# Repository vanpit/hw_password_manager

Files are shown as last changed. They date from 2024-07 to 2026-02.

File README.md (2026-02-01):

# Instrukcja managera haseł
Urządzenie posiada 3 przyciski: 
G - "góra"; 
D - "dół"; 
E - "enter";

W ekranie głównym: 
	G/D krótko - wybór slotu; 
	G długo - wejście w opcje slotu; 
	D długo - wypisanie starego hasła slotu; 
	E krótko - pisanie użytkownik [TAB] hasło [ENTER]; 
	E długo - pisanie samego hasła; 
	
W ekranie edycji slotu: 
	G/D krótko - wybór sekcji; 
	G długo - wejście w edycję pola; 
	D długo - anulowanie edycji slotu; 
	E długo na "przycisku" - wciśnięcie przycisku; 
	
W ekranie edycji pola tekstowego: 
	G/D krótko - zmiana literek; 
	E krótko - następna literka; 
	E długo na OK - zapisanie pola; 
	
W edycji/wpisywaniu PINu: 
	G/D krótko - wpisane 1 lub 0; 
	E długo na OK - zapisanie PINu; 

# Potrzebne elementy

Płytka ewaluacyjna  STM32F411 Black Pill

Wyświetlacz OLED SSD 1306

Mikroprzełączniki o oznaczeniu w TME B3U-1000PM

Kondensatory ceramiczne 0805 100nF

Przewody połączeniowe

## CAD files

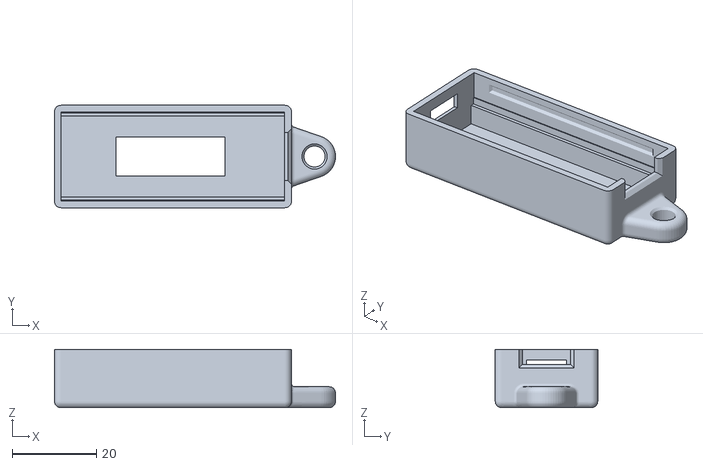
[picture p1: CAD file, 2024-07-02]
STL/Main case.stl
66.9 x 24.4 x 13.9

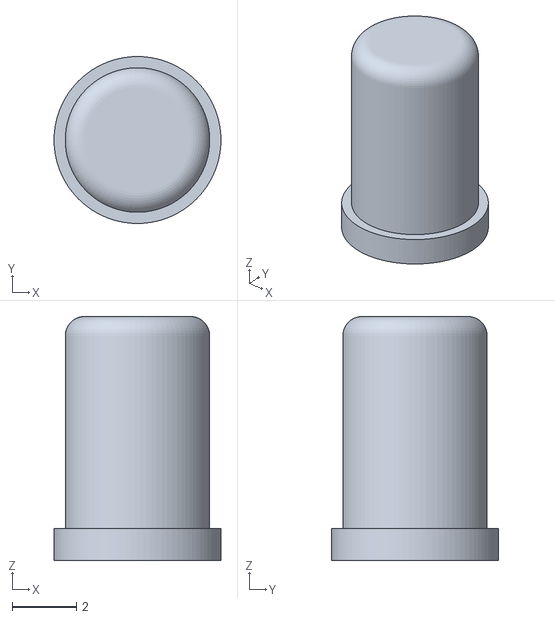
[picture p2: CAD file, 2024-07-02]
STL/Button 2.stl
5.20 x 5.20 x 7.60

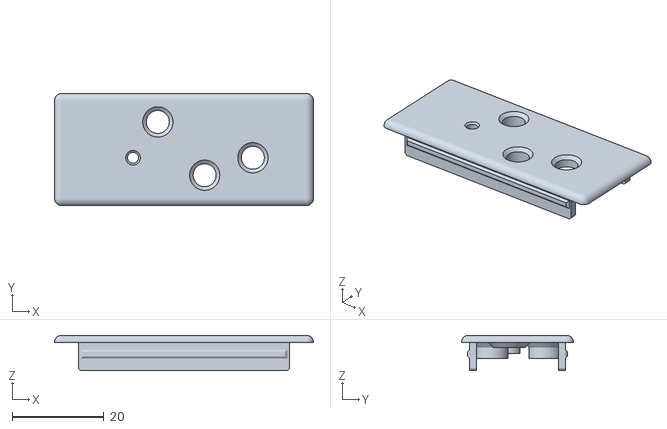
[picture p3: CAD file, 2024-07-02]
STL/Top case.stl
56.4 x 24.4 x 7.70

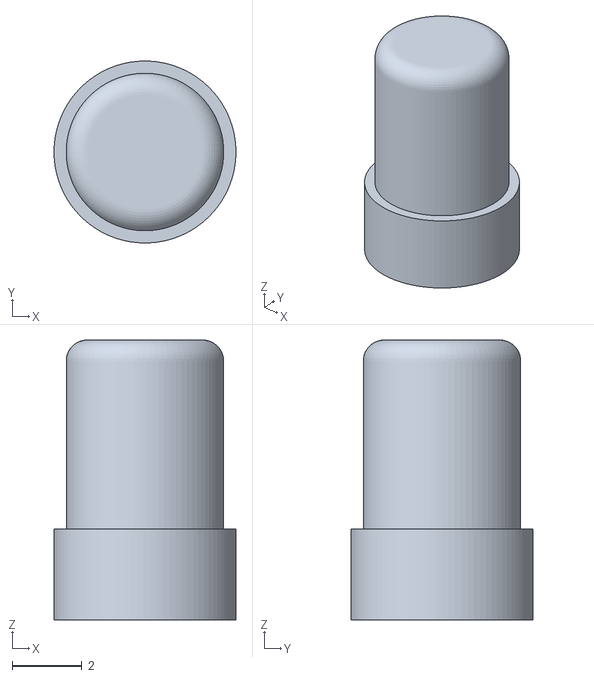
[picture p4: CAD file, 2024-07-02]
STL/Button.stl
5.20 x 5.20 x 8.00

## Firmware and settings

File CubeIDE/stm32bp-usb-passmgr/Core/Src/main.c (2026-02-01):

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
/* Includes ------------------------------------------------------------------*/
#include "main.h"
#include "adc.h"
#include "crc.h"
#include "dma.h"
#include "i2c.h"
#include "tim.h"
#include "usb_device.h"
#include "gpio.h"

/* USER CODE BEGIN Includes */

#include <stdbool.h>
#include "usbd_customhid.h"
#include "usb_hid_keys.h"
#include "OLED_SSD1306.h"
#include "GFX_BW.h"
#include "fonts/fonts.h"
#include "keystructures.h"
#include "database.h"


/* USER CODE END Includes */

/* USER CODE BEGIN PD */
#define VERSION_STRING "1.05"

#define BTN_PRESSED GPIO_PIN_RESET		// Buttons are active-low
#define BTN_RELEASED GPIO_PIN_SET

#define BTN0_GPIO GPIOA
#define BTN0_PIN GPIO_PIN_0

#define BTN1_GPIO GPIOB
#define BTN1_PIN GPIO_PIN_5

#define BTN2_GPIO GPIOA
#define BTN2_PIN GPIO_PIN_7

#define LED_ON GPIO_PIN_RESET			// LED is active-low
#define LED_OFF GPIO_PIN_SET

#define LED_GPIO GPIOC
#define LED_PIN GPIO_PIN_13

#define BUTTONS 3						// Number of onboard buttons

#define BUTTON_DEBOUNCE_COUNTER 3		// Debounce conter cycles
#define BUTTON_HOLD_COUNTER 50			// Hold detect conter cycles

#define KEYPRESS_EVERY_N_CYCLES 8		// Keypress every n cycles
#define KEYPRESS_RELEASE_AFTER_CYCLES 2	// Keypress every n cycles

#define NUMBER_OF_LCD_LINES 4

#define TYPE_SEQUENCE_OFF -1			// Disable typing sequence
#define TYPE_SEQUENCE_BEGIN 0			// Begin typing sequence

#define DISPLAY_CONTEXT_MAIN 0x00		// Display context password slots
#define DISPLAY_CONTEXT_SLOTEDIT 0x01	// Display context edit password slot
#define DISPLAY_CONTEXT_TEXTEDIT 0x02	// Display context edit text line
#define DISPLAY_CONTEXT_DELCONFIRM 0x03	// Display context confirm delete
#define DISPLAY_CONTEXT_MESSAGE 0x04	// Display context display message
#define DISPLAY_CONTEXT_PINSET 0x05		// Display context display message
#define DISPLAY_CONTEXT_PINENTER 0x06	// Display context display message
#define DISPLAY_CONTEXT_HLTMSG 0x07 	// Display content halt message

#define EDIT_LOT_ROLE_NAME 0x01
#define EDIT_LOT_ROLE_USERNAME 0x02
#define EDIT_LOT_ROLE_PASSWORD 0x03

#define EDIT_OPTION_NEWPASS 0x00		// Opcja edycji - Nowe hasło
#define EDIT_OPTION_SAVE 0x01			// Opcja edycji - Zapisz
#define EDIT_OPTION_DELETE 0x02			// Opcja edycji - Zapisz
#define EDIT_OPTION_NAME 0x03			// Opcja edycji - Nazwa
#define EDIT_OPTION_USERNAME 0x04		// Opcja edycji - Użytkownik
#define EDIT_OPTION_PASSWORD 0x05		// Opcja edycji - Hasło

#define MAX_LINE_OF_TEXT_CHARS 20

#define MSG_DISPLAY_CYCLES 150
#define VERSION_DISPLAY_CYCLES 70
#define DBMSG_DISPLAY_CYCLES 20
#define SAVE_ALL_SLOTS_ON_CYCLE 10

#define LCD_DIM_COUNTER_START 6000
#define DISPLAY_ENABLED_COUNTER_START 30000

#define LCD_DIM_BRIGHT_VALUE 0x50
#define LCD_DIM_DARK_VALUE 0x00

#define LCD_BRIGHTNESS_IS_DIM 0x01
#define LCD_BRIGHTNESS_GO_DIM 0x02
#define LCD_BRIGHTNESS_GO_BRIGHT 0x04

#define PIN_ENTER_CHAR_UNKNOWN '#'
#define PIN_ENTER_CHAR_UPARROW '^'
#define PIN_ENTER_CHAR_ONE '1'
#define PIN_ENTER_CHAR_ZERO '0'

#define MAX_FAILED_LOGIN 3

#define OPT_FAILED_LOGINS 0

#define DELAYED_LOGIN_COUNTER 10

void welcomeMsg(void);
void longPress(int);
void shortPress(int);
void loadAndDisplaySlots(void);
void loadSlotsFromFlash(void);
void displayLoadedSlots(void);
void cleanAndSaveDB(void);
bool saveAllSlots(void);
char alphabetGetNextChar(char);
char alphabetGetPreviousChar(char);
void sanitizeLineOfText(char*, int);
void randomizePassword(char*, int);
void loadEncryptedDatabase(void);
void scrambleEmptyData(char*, int);

/* USER CODE END PD */


/* USER CODE BEGIN PV */

extern USBD_HandleTypeDef hUsbDeviceFS;

struct ButtonState {
	bool isPressed;
	bool isHolded;
	bool awaitingPressAction;
	bool awaitingReleaseAction;
	bool awaitingLongAction;
	int stateCounter;
	int holdCounter;
	GPIO_TypeDef *GPIO;
	uint8_t PIN;
};

struct ButtonState buttonState[3] = {0};

char alphabet[] = {'a', 'b', 'c', 'd', 'e', 'f', 'g', 'h', 'i', 'j', 'k', 'l', 'm', 'n', 'o', 'p', 'q', 'r', 's', 't', 'u', 'v', 'w', 'x', 'y', 'z',
				   'A', 'B', 'C', 'D', 'E', 'F', 'G', 'H', 'I', 'J', 'K', 'L', 'M', 'N', 'O', 'P', 'Q', 'R', 'S', 'T', 'U', 'V', 'W', 'X', 'Y', 'Z',
				   '0', '1', '2', '3', '4', '5', '6', '7', '8', '9', '!', '@', '#', '$', '%', '^', '&', '*', '(', ')', '-', '=', '_', '+',
				   '.', 0x00};

int letterDisplay = sizeof(alphabet)-1;

const int releaseKey = 0;
const int userBegin = 1;
const int passwordBegin = 12;

int letterToType = 0;
int keyPressed = 0;

const int longPressCycles = 35;

uint8_t capslockState = 0;

uint8_t usbConnected = 0;

char slotDisplayLines[4][26] = {{0}, {0}, {0}, {0}};
char slotEditLines[4][26] = {{0}, {0}, {0}, {0}};
bool slotsWithLabel[4] = { false, false, false, false };
static char *slotEditNewPassBtn = "[Nowe]";
static char *slotEditSaveBtn = "[Zapisz]";
static char *slotEditDeleteBtn = "[Usun]";
static char *slotEditOKBtn = "[OK]";
static char *slotEditNameLabel = "N:";
static char *slotEditUsernameLabel = "U:";
static char *slotEditPasswordLabel = "H:";
int editOption = 0;

static char *slotEditLOTLabelName = "Nazwa:";
static char *slotEditLOTLabelUsername = "Uzytkownik:";
static char *slotEditLOTLabelPassword = "Haslo:";

static char *pinEditLabel = "Ustaw PIN:";
static char *pinEnterLabel = "Podaj PIN:";

char lcdMessage[16] = {0};

char str[20] = {0};

PasswordSlot passwordSlots[NUMBER_OF_SLOTS] = {0};
PasswordSlot currentEditPasswordSlot;
volatile bool editPasswordWasChanged = false;
bool slotValid[NUMBER_OF_SLOTS + 1] = { false };
char validSignature[4] = { 'E', 'O', 'D', 'B' };
uint8_t dbSignature[4] = {0};

static char *slotInvalidName = "[ DODAJ SLOT ]";
static char *slotSetPinName = "[ USTAW PIN ]";
static char *slotLabels[NUMBER_OF_SLOTS + 1] = {"1.", "2.", "3.", "4.", "5.", "6.", "7.", "8.", "9.",
											    "A.", "B.", "C.", "D.", "E.", "F.", "G.", "H.", "I.",
											    "J.", "K.", "L.", "M.", "N.", "O.", "P.", "Q.", "R.",
											    "S.", "T.", "U.", "W.", "X.", "Y.", "Z.", ".."};

static char *slotConfirmDeleteLabel = "[YARLY!]";

const char* lcdMessageTyping = "PISZE...";
const char* lcdMessageSaving = "Zapisuje...";
const char* lcdMessageDeleting = "Usuwam...";
const char* lcdMessageSaveError = "BLAD!";
const char* lcdMessageSaveOK = "OK!";

const char* lcdDelConfirmMessage = "ORLY???";

const char* lcdMessageLocked = "Blokada";
const char* lcdMessageFailedPin = "Zly PIN!";

const char* lcdMessageVersion = VERSION_STRING;

typedef struct EditedLineOfText {
	char line[25];
	char name[25];
	int lineRole;
	int editedChar;
} EditedLineOfText;

static char emptyChar = '~';
static char upArrowChar = '^';

int okButtonIdx = 0;

EditedLineOfText editedLineOfText = { {0}, {0}, 0, 0 };

volatile int selectedSlot = 0;

typedef struct TypeSequence {
	int lUsername;
	int lPassword;
	int lPreviousPassword;
	bool withTerminations;
} TypeSequence;

TypeSequence typeSequence = {-1, -1};

volatile uint8_t displayContext = DISPLAY_CONTEXT_MAIN;

volatile int messageDisplayCounter = 0;

uint8_t randomSeed[MAX_LINE_OF_TEXT_CHARS * 4] = {0};
volatile uint8_t currentSeedPart = 0;

volatile int lcdDimCounter = 0;

volatile uint8_t lcdBrightnessStatus = 0x00;

volatile int displayEnabledCounter = 0;

uint8_t displaySlotsFirst = {0};
uint8_t displaySlotsLast = {0};

uint8_t xorPinKey = 0x00;

volatile uint8_t pinEntered = 0x00;
volatile uint8_t pinEnterPos = 0;

uint8_t optBuffer[4];

volatile int delayedLogin = 0x00;

volatile bool btnCancelNextAction = false;

uint8_t databaseMode = PM_DATABASE_MODE_MAIN;
volatile uint8_t saveDatabasePending = false;

/* USER CODE END PV */

void SystemClock_Config(void);
/* USER CODE BEGIN 0 */

void welcomeMsg(void) {
	displayContext = DISPLAY_CONTEXT_MESSAGE;
	if (databaseMode == PM_DATABASE_MODE_BACKUP) {
		sprintf(lcdMessage, "baza zapas.");
	} else {
		sprintf(lcdMessage, "wersja %s", lcdMessageVersion);
	}
	messageDisplayCounter = VERSION_DISPLAY_CYCLES;
}

// Procedures executed on buttons long press
void longPress(int button) {

	if (btnCancelNextAction) {
		btnCancelNextAction = false;
		return;
	}

	switch (displayContext)
	{
		case DISPLAY_CONTEXT_MAIN:
			switch (button) {
				case 0:	// BUTTON 0 LONG PRESS
					if ((typeSequence.lUsername == TYPE_SEQUENCE_OFF) && (typeSequence.lPassword == TYPE_SEQUENCE_OFF) && (typeSequence.lPreviousPassword == TYPE_SEQUENCE_OFF) && slotValid[selectedSlot]) {
						typeSequence.lUsername = TYPE_SEQUENCE_OFF;
						typeSequence.lPassword = TYPE_SEQUENCE_BEGIN;
						typeSequence.lPreviousPassword = TYPE_SEQUENCE_OFF;
						typeSequence.withTerminations = false;
						keyPressed = 0;
						//Display typing message
						strcpy(lcdMessage, lcdMessageTyping);
						displayContext = DISPLAY_CONTEXT_MESSAGE;
					}
					break;
				case 1: // BUTTON 1 LONG PRESS
					if (selectedSlot > displaySlotsLast) {
						pinEntered = 0x00;
						pinEnterPos = 0x00;
						displayContext = DISPLAY_CONTEXT_PINSET;
					}
					else
					{
						if (slotValid[selectedSlot]) {
							strncpy(currentEditPasswordSlot.name, passwordSlots[selectedSlot].name, 25);
							strncpy(currentEditPasswordSlot.username, passwordSlots[selectedSlot].username, 25);
							strncpy(currentEditPasswordSlot.password, passwordSlots[selectedSlot].password, 25);
							strncpy(currentEditPasswordSlot.previouspassword, passwordSlots[selectedSlot].previouspassword, 25);
							sanitizeLineOfText(currentEditPasswordSlot.name, sizeof(currentEditPasswordSlot.name));
							sanitizeLineOfText(currentEditPasswordSlot.username, sizeof(currentEditPasswordSlot.username));
							sanitizeLineOfText(currentEditPasswordSlot.password, sizeof(currentEditPasswordSlot.password));
							sanitizeLineOfText(currentEditPasswordSlot.previouspassword, sizeof(currentEditPasswordSlot.previouspassword));
						} else {
							strcpy(currentEditPasswordSlot.name, "");
							strcpy(currentEditPasswordSlot.username, "");
							strcpy(currentEditPasswordSlot.password, "");
							strcpy(currentEditPasswordSlot.previouspassword, "");
						}
						displayContext = DISPLAY_CONTEXT_SLOTEDIT;
						editOption = EDIT_OPTION_NEWPASS;
						editPasswordWasChanged = false;
					}
					break;
				case 2: // BUTTON 2 LONG PRESS
					if ((typeSequence.lUsername == TYPE_SEQUENCE_OFF) && (typeSequence.lPassword == TYPE_SEQUENCE_OFF) && (typeSequence.lPreviousPassword == TYPE_SEQUENCE_OFF) && slotValid[selectedSlot]) {
						typeSequence.lUsername = TYPE_SEQUENCE_OFF;
						typeSequence.lPassword = TYPE_SEQUENCE_OFF;
						typeSequence.lPreviousPassword = TYPE_SEQUENCE_BEGIN;
						typeSequence.withTerminations = false;
						keyPressed = 0;
						//Display typing message
						strcpy(lcdMessage, lcdMessageTyping);
						displayContext = DISPLAY_CONTEXT_MESSAGE;
					}
					break;
			}
			break;

		case DISPLAY_CONTEXT_SLOTEDIT:
			switch (button) {
				case 0:	// BUTTON 0 LONG PRESS
					if ((editOption == EDIT_OPTION_SAVE) || (editOption == EDIT_OPTION_NEWPASS) || (editOption == EDIT_OPTION_DELETE)) {
						sanitizeLineOfText(currentEditPasswordSlot.name, sizeof(currentEditPasswordSlot.name));
						sanitizeLineOfText(currentEditPasswordSlot.username, sizeof(currentEditPasswordSlot.username));
						sanitizeLineOfText(currentEditPasswordSlot.password, sizeof(currentEditPasswordSlot.password));
						sanitizeLineOfText(currentEditPasswordSlot.previouspassword, sizeof(currentEditPasswordSlot.previouspassword));

						switch (editOption)
						{
							case EDIT_OPTION_SAVE:
								strncpy(passwordSlots[selectedSlot].name, currentEditPasswordSlot.name, sizeof(currentEditPasswordSlot.name));
								strncpy(passwordSlots[selectedSlot].username, currentEditPasswordSlot.username,  sizeof(currentEditPasswordSlot.username));
								if (editPasswordWasChanged)
								{
									strncpy(passwordSlots[selectedSlot].previouspassword, passwordSlots[selectedSlot].password,  sizeof(passwordSlots[selectedSlot].password));
									sanitizeLineOfText(passwordSlots[selectedSlot].previouspassword, sizeof(passwordSlots[selectedSlot].previouspassword));
								}
								strncpy(passwordSlots[selectedSlot].password, currentEditPasswordSlot.password,  sizeof(currentEditPasswordSlot.password));
								slotValid[selectedSlot] = true;
								saveDatabasePending = true;
								strcpy(lcdMessage, lcdMessageSaving);
								displayContext = DISPLAY_CONTEXT_MESSAGE;
								messageDisplayCounter = DBMSG_DISPLAY_CYCLES;
								editPasswordWasChanged = false;
								break;

							case EDIT_OPTION_NEWPASS:
								randomizePassword(currentEditPasswordSlot.password, MAX_LINE_OF_TEXT_CHARS);
								sanitizeLineOfText(currentEditPasswordSlot.password, sizeof(currentEditPasswordSlot.password));
								editPasswordWasChanged = true;
								break;
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
int main(void)
{
  /* MCU Configuration--------------------------------------------------------*/

  /* Reset of all peripherals, Initializes the Flash interface and the Systick. */
  HAL_Init();

  /* USER CODE BEGIN Init */
  //__HAL_TIM_ENABLE_IT(htim, TIM_IT_UPDATE);

  /* USER CODE END Init */

  /* Configure the system clock */
  SystemClock_Config();

  /* Initialize all configured peripherals */
  MX_GPIO_Init();
  MX_DMA_Init();
  MX_TIM10_Init();
  MX_USB_DEVICE_Init();
  MX_I2C1_Init();
  MX_CRC_Init();
  MX_ADC1_Init();
  /* USER CODE BEGIN 2 */

  // Initialize main timer - tim10
  HAL_TIM_Base_Start_IT(&htim10);

  // Disable onboard LED
  HAL_GPIO_WritePin(LED_GPIO, LED_PIN, LED_OFF);

  // Btn GND to LOW
  //HAL_GPIO_WritePin(GPIOA, GPIO_PIN_6, GPIO_PIN_RESET);
  //HAL_GPIO_WritePin(GPIOB, GPIO_PIN_4, GPIO_PIN_RESET);

  // OLED display INIT

  SSD1306_I2cInit(&hi2c1);
  SSD1306_SetContrast(LCD_DIM_BRIGHT_VALUE);
  lcdDimCounter = LCD_DIM_COUNTER_START;
  displayEnabledCounter = DISPLAY_ENABLED_COUNTER_START;
  btnCancelNextAction = false;

  SSD1306_RotateDisplay(0);
  //SSD1306_RotateDisplay(1);
  SSD1306_ZoomIn(1);
  GFX_SetFont(font_8x5);

  // Configure buttons structures
  buttonState[0].GPIO = BTN0_GPIO;
  buttonState[0].PIN = BTN0_PIN;
  buttonState[1].GPIO = BTN1_GPIO;
  buttonState[1].PIN = BTN1_PIN;
  buttonState[2].GPIO = BTN2_GPIO;
  buttonState[2].PIN = BTN2_PIN;

  HAL_Delay(50);

  GPIO_PinState initbtnstate1 = HAL_GPIO_ReadPin(buttonState[1].GPIO, buttonState[1].PIN);
  GPIO_PinState initbtnstate2 = HAL_GPIO_ReadPin(buttonState[2].GPIO, buttonState[2].PIN);

  if ((initbtnstate1 == BTN_PRESSED) && (initbtnstate2 == BTN_PRESSED)) {
	  databaseMode = PM_DATABASE_MODE_BACKUP;
  }

  selectedSlot = 0;

  GetOptions(optBuffer);

  if (*((uint32_t*)optBuffer) == 0xFFFFFFFF)
  {
	  for (int i = 0; i < sizeof(optBuffer); i++) optBuffer[i] = 0x00;
	  SaveOptions(optBuffer);
  }

  if (optBuffer[OPT_FAILED_LOGINS] < MAX_FAILED_LOGIN) {

	  // Load DB signature
	  GetDBSignature(dbSignature, NUMBER_OF_SLOTS, xorPinKey, databaseMode);

	  uint32_t *tmpSignature = (uint32_t*)dbSignature;
	  if (*tmpSignature == 0xFFFFFFFF )
	  {
		  // DATABSE UNINTIALIZED
		  cleanAndSaveDB();
		  loadAndDisplaySlots();
		  welcomeMsg();
	  }
	  else if (*tmpSignature == *((uint32_t*)validSignature))
	  {
		  // DATABSE OK NO PASSWORD
		  loadAndDisplaySlots();
		  welcomeMsg();
	  }
	  else
	  {
		  displayContext = DISPLAY_CONTEXT_PINENTER;
		  pinEntered = 0x00;
		  pinEnterPos = 0x00;
	  }
  }
  else
  {
	  strcpy(lcdMessage, lcdMessageLocked);
	  displayContext = DISPLAY_CONTEXT_HLTMSG;
  }

  saveDatabasePending = false;

  /* USER CODE END 2 */

  /* Infinite loop */
  /* USER CODE BEGIN WHILE */
  while (1)
  {

		#ifdef SSD1306_I2C_DMA_ENABLE
		if(hi2c1.hdmatx->State == HAL_DMA_STATE_READY) {
		#endif

			if (lcdBrightnessStatus & LCD_BRIGHTNESS_GO_DIM) {
				SSD1306_SetContrast(LCD_DIM_DARK_VALUE);
				lcdBrightnessStatus &= ~LCD_BRIGHTNESS_GO_DIM;
				lcdBrightnessStatus |= LCD_BRIGHTNESS_IS_DIM;
			}

			if (lcdBrightnessStatus & LCD_BRIGHTNESS_GO_BRIGHT) {
				SSD1306_SetContrast(LCD_DIM_BRIGHT_VALUE);
				lcdBrightnessStatus &= ~LCD_BRIGHTNESS_GO_BRIGHT;
				lcdBrightnessStatus &= ~LCD_BRIGHTNESS_IS_DIM;
			}

			SSD1306_Clear(BLACK);

		if (displayEnabledCounter > 0) {

			switch (displayContext)
			{

				case DISPLAY_CONTEXT_MAIN:
					GFX_SetFontSize(1);

					for (int i = 0; i < NUMBER_OF_LCD_LINES; i++) {
						if (strlen(slotDisplayLines[i]) > 0) {
							if (slotsWithLabel[i]) GFX_DrawString(0, 8 * i, slotLabels[i+displaySlotsFirst], (selectedSlot == i+displaySlotsFirst)?BLACK:WHITE, (selectedSlot == i+displaySlotsFirst)?WHITE:BLACK);
							else GFX_DrawString(0, 8 * i, slotLabels[NUMBER_OF_SLOTS], (selectedSlot == i+displaySlotsFirst)?BLACK:WHITE, (selectedSlot == i+displaySlotsFirst)?WHITE:BLACK);
							GFX_DrawString(16, 8 * i, slotDisplayLines[i], WHITE, BLACK);
						}
					}

					break;

				case DISPLAY_CONTEXT_SLOTEDIT:
					GFX_SetFontSize(1);

					GFX_DrawString(0, 0, slotEditNameLabel, (editOption == EDIT_OPTION_NAME)?BLACK:WHITE, (editOption == EDIT_OPTION_NAME)?WHITE:BLACK);
					GFX_DrawString(0, 8, slotEditUsernameLabel, (editOption == EDIT_OPTION_USERNAME)?BLACK:WHITE, (editOption == EDIT_OPTION_USERNAME)?WHITE:BLACK);
					GFX_DrawString(0, 16, slotEditPasswordLabel, (editOption == EDIT_OPTION_PASSWORD)?BLACK:WHITE, (editOption == EDIT_OPTION_PASSWORD)?WHITE:BLACK);

					GFX_DrawString(0, 24, slotEditNewPassBtn, (editOption == EDIT_OPTION_NEWPASS)?BLACK:WHITE, (editOption == EDIT_OPTION_NEWPASS)?WHITE:BLACK);
					GFX_DrawString(39, 24, slotEditSaveBtn, (editOption == EDIT_OPTION_SAVE)?BLACK:WHITE, (editOption == EDIT_OPTION_SAVE)?WHITE:BLACK);
					GFX_DrawString(90, 24, slotEditDeleteBtn, (editOption == EDIT_OPTION_DELETE)?BLACK:WHITE, (editOption == EDIT_OPTION_DELETE)?WHITE:BLACK);

					GFX_DrawString(12, 0, currentEditPasswordSlot.name, WHITE, BLACK);
					GFX_DrawString(12, 8, currentEditPasswordSlot.username, WHITE, BLACK);
					GFX_DrawString(12, 16, currentEditPasswordSlot.password, WHITE, BLACK);

					break;

				case DISPLAY_CONTEXT_TEXTEDIT:
					GFX_SetFontSize(1);

					okButtonIdx = (strlen(editedLineOfText.line) + 1 < MAX_LINE_OF_TEXT_CHARS)?strlen(editedLineOfText.line) + 1:MAX_LINE_OF_TEXT_CHARS;

					GFX_DrawString(0, 0, editedLineOfText.name, WHITE, BLACK);
					GFX_DrawString(100, 0, slotEditOKBtn, (editedLineOfText.editedChar == okButtonIdx)?BLACK:WHITE, (editedLineOfText.editedChar == okButtonIdx)?WHITE:BLACK);

					bool charsValid = true;

					for (int i = 0; i< okButtonIdx; i++) {
						if (editedLineOfText.line[i] == 0x00) charsValid = false;
						if (charsValid) GFX_DrawChar(i * 6, 16, editedLineOfText.line[i], WHITE, BLACK);
						else GFX_DrawChar(i * 6, 16, emptyChar, WHITE, BLACK);
						if (editedLineOfText.editedChar == i) GFX_DrawChar(i * 6, 26, upArrowChar, WHITE, BLACK);
					}

					break;

				case DISPLAY_CONTEXT_DELCONFIRM:

					GFX_SetFontSize(2);
					GFX_DrawString(0,8, lcdMessage, WHITE, BLACK);

					GFX_SetFontSize(1);
					GFX_DrawString(80,24, slotConfirmDeleteLabel, BLACK, WHITE);

					break;

				case DISPLAY_CONTEXT_MESSAGE:

					GFX_SetFontSize(2);
					GFX_DrawString(0,8, lcdMessage, WHITE, BLACK);

					break;

				case DISPLAY_CONTEXT_PINSET:

					GFX_SetFontSize(1);
					GFX_DrawString(0, 0, pinEditLabel, WHITE, BLACK);

					GFX_DrawString(100, 0, slotEditOKBtn, (pinEnterPos > 7)?BLACK:WHITE, (pinEnterPos > 7)?WHITE:BLACK);

					for (int i = 0; i < 8; i++)
					{
						GFX_SetFontSize(2);
						if (i<pinEnterPos)
						{
							GFX_DrawChar(17 + i * 11, 12, (pinEntered >> (7 - i) & 0x01)?PIN_ENTER_CHAR_ONE:PIN_ENTER_CHAR_ZERO , WHITE, BLACK);
						}
						else
						{
							GFX_DrawChar(17 + i * 11, 12, PIN_ENTER_CHAR_UNKNOWN, WHITE, BLACK);
						}
						if (pinEnterPos == i)
						{
							GFX_SetFontSize(1);
							GFX_DrawChar(19 + i * 11, 28, PIN_ENTER_CHAR_UPARROW, WHITE, BLACK);
						}
					}
					break;

				case DISPLAY_CONTEXT_PINENTER:

					GFX_SetFontSize(1);
					GFX_DrawString(0, 0, pinEnterLabel, WHITE, BLACK);
					sprintf(str, "(%d/%d)", optBuffer[0]+1, MAX_FAILED_LOGIN);
					GFX_DrawString(90, 0, str, WHITE, BLACK);

					for (int i = 0; i < 8; i++)
					{
						GFX_SetFontSize(2);
						if (i<pinEnterPos)
						{
							GFX_DrawChar(17 + i * 11, 12, (pinEntered >> (7 - i) & 0x01)?PIN_ENTER_CHAR_ONE:PIN_ENTER_CHAR_ZERO , WHITE, BLACK);
						}
						else
						{
							GFX_DrawChar(17 + i * 11, 12, PIN_ENTER_CHAR_UNKNOWN, WHITE, BLACK);
						}
						if (pinEnterPos == i)
						{
							GFX_SetFontSize(1);
							GFX_DrawChar(19 + i * 11, 28, PIN_ENTER_CHAR_UPARROW, WHITE, BLACK);
						}
					}
					break;

				case DISPLAY_CONTEXT_HLTMSG:

					GFX_SetFontSize(2);
					GFX_DrawString(0,8, lcdMessage, WHITE, BLACK);

					break;

				}

			}

			SSD1306_Display();

		#if  defined(SSD1306_I2C_DMA_ENABLE) || defined(SSD1306_SPI_DMA_ENABLE)
		}
		#endif

	HAL_Delay(50);
    /* USER CODE END WHILE */

    /* USER CODE BEGIN 3 */
  }
  /* USER CODE END 3 */
}

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
/* USER CODE BEGIN 4 */

// Caps lock internal status procedure used to remember if caps-lock disable code should be issued before typing username/pasword
void setCapslockState(uint8_t state) {
	capslockState = state;
	if (capslockState) {
		HAL_GPIO_WritePin(LED_GPIO, LED_PIN, LED_ON);
	} else {
		HAL_GPIO_WritePin(LED_GPIO, LED_PIN, LED_OFF);
	}
}

void resetCapslockState(void) {
	uint8_t *rep = GetReportByChar(SEQ_CAPSLOCK);
	USBD_CUSTOM_HID_SendReport(&hUsbDeviceFS, rep, sizeof(KbdReport));
}
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

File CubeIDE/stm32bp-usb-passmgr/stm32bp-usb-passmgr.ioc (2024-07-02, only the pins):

Mcu.UserName=STM32F411CEUx
PA0-WKUP.GPIO_Label=KEY User
PA0-WKUP.Signal=GPXTI0
PA11.Signal=USB_OTG_FS_DM
PA12.Signal=USB_OTG_FS_DP
PA6.Signal=GPIO_Input
PA7.GPIO_Label=Button A
PA7.Signal=GPXTI7
PB4.Signal=GPIO_Input
PB5.GPIO_Label=Button B
PB5.Signal=GPXTI5
PB6.Signal=I2C1_SCL
PB7.Signal=I2C1_SDA
PC13-ANTI_TAMP.GPIO_Label=LED Blue
PC13-ANTI_TAMP.Signal=GPIO_Output
PC14-OSC32_IN.Signal=RCC_OSC32_IN
PC15-OSC32_OUT.Signal=RCC_OSC32_OUT

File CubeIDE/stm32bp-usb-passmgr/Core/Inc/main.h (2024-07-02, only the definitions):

#define LED_Blue_Pin GPIO_PIN_13
#define LED_Blue_GPIO_Port GPIOC
#define KEY_User_Pin GPIO_PIN_0
#define KEY_User_GPIO_Port GPIOA
#define KEY_User_EXTI_IRQn EXTI0_IRQn
#define Button_A_Pin GPIO_PIN_7
#define Button_A_GPIO_Port GPIOA
#define Button_A_EXTI_IRQn EXTI9_5_IRQn
#define Button_B_Pin GPIO_PIN_5
#define Button_B_GPIO_Port GPIOB
#define Button_B_EXTI_IRQn EXTI9_5_IRQn

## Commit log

2024-07-02 Initial commit.
    Initial commit of 1.04 firmware.
    [Button 2.stl, Button.stl, Main case.stl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]
2024-07-02 Added manual and BOM
2026-02-01 1.05 patch release
    - fixed off-by-one error in randomSeed[currentSeedPart]
    - improved password RNG
    - added 'v' and 'V' letters to alphabet
    [OLED_SSD1306.c, main.c]

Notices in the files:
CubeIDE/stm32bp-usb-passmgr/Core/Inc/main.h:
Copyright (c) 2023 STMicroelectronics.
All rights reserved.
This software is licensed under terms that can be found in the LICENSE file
